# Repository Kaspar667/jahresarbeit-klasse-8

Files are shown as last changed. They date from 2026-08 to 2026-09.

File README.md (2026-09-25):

# Jahresarbeit: Bau einer Kamera-Drohne

Jahresarbeit der 8. Klasse an der Rudolf Steiner Schule Berlin (Dahlem).

Ein selbst gewähltes Projekt aus **Theorie und Praxis**: über mehrere Monate wird
eine Kamera-Drohne entwickelt und gebaut, dokumentiert und am Ende vor der
Schulgemeinschaft präsentiert.

## Aufbau in drei Schritten

Das Projekt nähert sich der fertigen Kamera-Drohne in drei aufeinander aufbauenden
Stufen — von einfach zu komplex:

| Schritt | Projekt | Ordner | Ziel |
|---:|---|---|---|
| 1 | Holz-Bausatz (Amazon) | [`01-holzbausatz/`](01-holzbausatz/) | Erste Erfahrungen: Zusammenbau, Motoren, Propeller, Fliegen lernen |
| 2 | ESP-FLY (ESP32-S3) | [`02-esp-fly/`](02-esp-fly/) | Eigene Flugsoftware verstehen: Firmware bauen, flashen, Sensor & Steuerung |
| 3 | Eigenbau-Drohne | [`03-kamera-drohne/`](03-kamera-drohne/) | Selbst entworfen: gefräster Kohlefaserrahmen, eigene Trägerplatine, bürstenlose Motoren |

## Ordnerstruktur

```
jahresarbeit-drohne/
├── README.md              ← dieses Dokument (Überblick)
├── docs/                  ← schriftliche Ausarbeitung, Notizen, Präsentation
├── 01-holzbausatz/        ← Schritt 1
├── 02-esp-fly/            ← Schritt 2 (enthält Firmware als Git-Submodul)
└── 03-kamera-drohne/      ← Schritt 3
```

## Stand (25.09.2026)

Schritt 1 und 2 sind gebaut und geflogen. Schritt 3 ist **durchgeplant**: Auslegung,
Antrieb, Elektronik und die eigene Trägerplatine sind entschieden und begründet, Motoren
und Regler bestellt. Gebaut ist davon noch nichts — die Kapitel in
[`03-kamera-drohne/`](03-kamera-drohne/) halten fest, *warum* welches Teil gewählt wurde.

## Schriftliche Arbeit

Die Ausarbeitung liegt in [`docs/`](docs/). Jeder Bauschritt hat außerdem eine
eigene `README.md` im jeweiligen Ordner, in der Vorgehen, Probleme und Lösungen
festgehalten werden — das bildet später das Rückgrat der schriftlichen Arbeit.

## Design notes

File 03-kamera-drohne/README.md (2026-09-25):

# Schritt 3 — Eigenbau-Drohne (Abschlusswerk)

Das praktische Hauptwerk der Jahresarbeit: eine Drohne, die **nicht gekauft, sondern
entworfen** wird. Rahmen selbst gefräst, Trägerplatine selbst entworfen und gefräst,
Flugsoftware selbst konfiguriert.

Im Gegensatz zu Schritt 1 (fertiger Bausatz) und Schritt 2 (fertiges Board, eigene
Firmware) wird hier **jedes Teil bewusst ausgewählt und die Auswahl begründet**. Genau
diese Begründungen sind der Stoff der schriftlichen Arbeit — nicht die Bauanleitung.

## Der Stand in einem Absatz

Geplant ist ein **Quadrocopter mit 9 × 9 cm Kohlefaserrahmen**, ausgelegt nicht auf Schub,
sondern auf **Ausdauer**: Ziel sind 15–30 Minuten Flugzeit, realistisch geschätzt 11–19.
Angetrieben von vier bürstenlosen 1204-Motoren an einem gekauften 4-in-1-Regler, gesteuert
von einem **Seeed XIAO ESP32-S3** (demselben Mikrocontroller wie in Schritt 2) mit der
offenen Flugsoftware **ESP-FC**. Dazwischen sitzt eine **selbst entworfene Trägerplatine**,
die auf der CNC-Fräse 1310 hergestellt wird. Motoren und Regler sind bestellt
(23.09.2026), die Steuerungsseite noch nicht.

## Die Kapitel

| Datei | Inhalt |
|---|---|
| [`01-auslegung.md`](01-auslegung.md) | Rahmen, Propellergröße, Flugzeit — warum 9 × 9 cm alles andere festlegt |
| [`02-antrieb.md`](02-antrieb.md) | Motoren, Regler, Akku — und warum es 2S werden musste |
| [`03-elektronik.md`](03-elektronik.md) | XIAO ESP32-S3, ESP-FC, Pinbelegung, Fernsteuerung |
| [`04-traegerplatine.md`](04-traegerplatine.md) | Die eigene Platine: Entwurf, Schaltplan, Bauteile |
| [`05-bestellliste.md`](05-bestellliste.md) | Was bestellt ist, was noch fehlt |
| [`06-bauplan.md`](06-bauplan.md) | Alle Schritte von der Bestellung bis zum ersten Flug |
| [`cad/`](cad/) | Rahmen als 3D-Modell (STEP, DXF zum Fräsen, STL) |

## Die sechs Entscheidungen, um die es geht

Wer die Arbeit schreibt, braucht vor allem diese sechs — jede ist eine Abwägung, keine
Geschmacksfrage.

**1. Ausdauer statt Schub.** Man kann dieselbe Baugröße auf Beschleunigung auslegen
(Renn-Drohne, 2 Minuten Flugzeit) oder auf lange Flugzeit. Entschieden: Ausdauer. Das legt
Akkutyp (Lithium-Ionen-Rundzellen statt LiPo), Propellersteigung und Motorwahl fest.

**2. 9 × 9 cm — und damit keine 3-Zoll-Propeller.** Der Fräsbereich der 1310 gibt die
Rahmengröße vor. Daraus folgt durch reine Geometrie, dass 3-Zoll-Propeller sich
überschneiden würden. Es werden 2,8 Zoll. → [`01-auslegung.md`](01-auslegung.md)

**3. Eigene Steuerplatine statt fertiger Flugsteuerung.** Nicht aus Ehrgeiz: ein Kreisel,
der an fliegenden Drähten hängt, misst die Schwingung der Drähte mit und lässt sich nicht
abstimmen. → [`04-traegerplatine.md`](04-traegerplatine.md)

**4. Zwei Akkuzellen (2S) statt einer.** Folgt zwangsläufig aus Entscheidung 3: getrennte
Regler, wie sie ein eigenes Board braucht, gibt es im Handel erst ab zwei Zellen. Kostet
etwa 15 % Flugzeit — das ist der Preis für den eigenen Entwurf.
→ [`02-antrieb.md`](02-antrieb.md)

**5. Kreisel über I2C, nicht SPI.** Der XIAO hat nur elf nutzbare Anschlüsse. SPI wäre
schneller, würde aber vier davon verbrauchen — dann bliebe kein Platz mehr für Barometer
und Summer. → [`03-elektronik.md`](03-elektronik.md)

**6. Der Ausbau in drei Stufen.** Einen bürstenlosen Regler von Grund auf zu bauen ist ein
eigenes Projekt. Deshalb gestaffelt, und **jede Stufe fliegt für sich**:

- **Stufe 1 — eigene Trägerplatine, gekaufter Regler.** ← *hier stehen wir*
- **Stufe 2 — eigener Regler** mit der offenen AM32-Firmware.
- **Stufe 3 — Gestensteuerung** über Raspberry Pi mit Kamera.

## Die Kamera: erst später (Stand 25.09.2026)

Der Projekttitel heißt „Kamera-Drohne", **Version 1 fliegt aber bewusst ohne Kamera.** Erst
soll das Fluggerät selbst sauber fliegen, dann kommt die Kamera dazu. Geplant ist dann
**analoges FPV**: Nano-Kamera, 5,8-GHz-Videosender (25 mW), Videobrille mit Rekorder.
Das kostet ~8 g und etwa 10 % Flugzeit.

Damit das später ohne Umbau geht, bekommt die Trägerplatine **schon jetzt** einen stärkeren
5-V-Regler (≥ 1,5 A) und einen Anschluss für Kamera und Sender. Kamera und Sender brauchen
keinen GPIO, die Pinbelegung bleibt gleich. Einzelheiten in
[`05-bestellliste.md`](05-bestellliste.md).

Für Stufe 3 (Gestensteuerung) kommt ohnehin eine Kamera am **Boden** dazu, auf einem
Raspberry Pi, der Kaspars Handbewegungen erkennt.

## Was als Nächstes passiert

1. Dicke der vorhandenen Kohlefaserplatte prüfen (soll 2,5 mm sein).
2. Rahmen in CAD zeichnen: 90 × 90 mm, Motorachsen 7,5 mm von den Kanten, vorne Platz für einen späteren Kamerahalter lassen.
3. Trägerplatine layouten und auf der 1310 fräsen.
4. Fehlende Teile nach der [Einkaufsliste](05-bestellliste.md) bestellen, das Kreiselmodul zuerst, ohne das fliegt nichts.
5. Ersten Rahmen fräsen und die Steifigkeit messen (Zielwert unter 6 mm Auslenkung).

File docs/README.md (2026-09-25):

# Schriftliche Ausarbeitung

Hier entsteht der schriftliche Teil der Jahresarbeit.

Vorschlag für die Gliederung:

1. **Einleitung** — Warum eine Kamera-Drohne? Persönliche Motivation.
2. **Grundlagen** — Wie fliegt eine Drohne? (Auftrieb, 4 Motoren, Gyroskop/IMU, Steuerung)
3. **Schritt 1 — Holz-Bausatz** — Aufbau, was funktioniert hat, was nicht.
4. **Schritt 2 — ESP-FLY** — eigene Firmware, Mikrocontroller (ESP32-S3), Sensor, Flashen.
5. **Schritt 3 — Eigenbau-Drohne** — Planung, Bau, Ergebnis. Das umfangreichste Kapitel;
   Material und Begründungen liegen in [`../03-kamera-drohne/`](../03-kamera-drohne/):
   - Auslegung: warum die Rahmengröße alles andere festlegt
   - Antrieb: bürstenlos statt Bürsten, und warum daraus zwei Akkuzellen folgen
   - Elektronik: derselbe Mikrocontroller wie in Schritt 2, andere Software
   - Die eigene Trägerplatine: Entwurf, Schaltplan, Fertigung auf der Fräse
6. **Reflexion** — Was habe ich gelernt? Was würde ich anders machen?
7. **Quellen**

Bilder und Videos gehören in einen Unterordner `docs/bilder/`.

## Hinweis zu Schritt 3

Die Kapiteldateien in `03-kamera-drohne/` sind bewusst so geschrieben, dass jede
Entscheidung eine **Begründung und eine verworfene Alternative** hat. Genau das ist der
Stoff, aus dem die schriftliche Arbeit besteht — eine reine Bauanleitung wäre zu wenig.

Besonders ergiebige Stellen:

- **Geometrie:** dass 3-Zoll-Propeller auf 9 × 9 cm nicht passen, lässt sich vorrechnen.
- **Folgekosten einer Entscheidung:** die eigene Platine erzwingt 2S und kostet dadurch
  ~15 % Flugzeit.
- **Datenblatt gegen Messung:** eine Akkuzelle mit 52 A Angabe schafft real 25 A.
- **Eigene Messung:** Rahmensteifigkeit (1,13 kg am Motorträger, Zielwert unter 6 mm) und
  die tatsächliche Flugzeit im Vergleich zur Vorhersage von 11–19 min.
- **Lehre aus Schritt 1:** warum ein Quadrocopter überhaupt zwei Drehrichtungen braucht —
  der Holz-Bausatz drehte sich ständig um die Hochachse, weil sich die Drehmomente nicht
  aufhoben.

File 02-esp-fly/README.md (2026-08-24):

# Schritt 2 — ESP-FLY (ESP32-S3)

Die [ESP-FLY](https://github.com/Seeed-Projects/Co-Create_ESP-FLY) ist eine winzige
Drohne auf Basis des Mikrocontrollers **Seeed XIAO ESP32-S3**. In diesem Schritt
geht es nicht nur ums Bauen, sondern darum, die **Flugsoftware (Firmware) selbst
zu verstehen, anzupassen und auf die Drohne zu spielen**.

## Was hier drin ist

- **`esp-drone/`** — die Firmware als **Git-Submodul** auf unseren Fork
  [`spieker/esp-drone`](https://github.com/spieker/esp-drone), Branch
  `jahresarbeit-klasse-8`. Hier stehen unsere board-spezifischen Anpassungen.
- **`esp-idf/`** — die Bau-Umgebung von Espressif als **Git-Submodul**,
  fest auf **v5.0** gepinnt (die Version, mit der es funktioniert).
- **`flash.sh`** — spielt die gebaute Firmware auf die Drohne (per USB).
- **`BUILD.md`** — die ausführliche Schritt-für-Schritt-Anleitung.

## Kurzanleitung

Ausführlich in **[BUILD.md](BUILD.md)**. In Kürze:

```bash
# 1. Projekt inkl. Submodule holen (falls noch nicht geschehen)
git submodule update --init --recursive     # laedt esp-drone + esp-idf (~1,7 GB)

# 2. ESP-IDF einmalig einrichten
cd esp-idf && ./install.sh esp32s3 && cd ..

# 3. Firmware bauen
cd esp-drone
. ../esp-idf/export.sh
idf.py set-target esp32s3        # zieht die ESP-FLY-Pins aus sdkconfig.defaults.esp32s3
idf.py build
cd ..

# 4. Drohne per USB anstecken, dann flashen
./flash.sh                       # findet ESP-IDF und Port automatisch
```

Zum Fliegen: Handy ins WLAN `ESP-DRONE_...` (Passwort `12345678`), dann die
**ESP-Drone App** öffnen und verbinden.

## Unsere Anpassungen (das Wichtigste zum Dokumentieren)

Die Standard-Firmware von Espressif geht von *anderen* Pins aus als das
ESP-FLY-Board. Ergebnis: der Bewegungssensor (MPU6050) meldete beim Start
`MPU6050 I2C connection [FAIL]`, und die App konnte sich nicht verbinden.

Lösung — in `esp-drone/sdkconfig.defaults.esp32s3` die richtigen Pins des
ESP-FLY-Boards eingetragen:

| Bauteil | Signal | GPIO |
|---|---|-----:|
| MPU6050 (Sensor) | I2C SDA | 5 |
| MPU6050 (Sensor) | I2C SCL | 6 |
| MPU6050 (Sensor) | INT | 8 |
| Motor 1 | PWM | 7 |
| Motor 2 | PWM | 4 |
| Motor 3 | PWM | 3 |
| Motor 4 | PWM | 1 |

Motortyp: brushed **715**. Danach: `MPU6050 I2C connection [OK]` — Sensor läuft,
App verbindet sich, Drohne fliegt.

> **Lernpunkt:** Software muss zur konkreten Hardware passen. Derselbe Programmcode
> funktioniert erst, wenn er weiß, an welchen Anschlüssen (Pins) des Chips die
> Bauteile wirklich hängen.

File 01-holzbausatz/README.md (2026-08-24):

# Schritt 1 — Holz-Bausatz (Amazon)

Der Einstieg: ein günstiger Drohnen-Bausatz aus Holz.

## Ziel
Erste Erfahrungen mit dem Aufbau einer Drohne sammeln — Rahmen, Motoren,
Propeller, Akku, Steuerung — und das Fliegen üben.

## Zu dokumentieren
- Welcher Bausatz? (Link / Bestellnummer)
- Aufbau: Was war einfach, was schwierig?
- Erster Flugversuch: Wie lief es?
- Was hat dieser Schritt für die nächsten gebracht?

## Fotos
In `bilder/` ablegen.

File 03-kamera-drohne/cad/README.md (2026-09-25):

# CAD: Rahmen

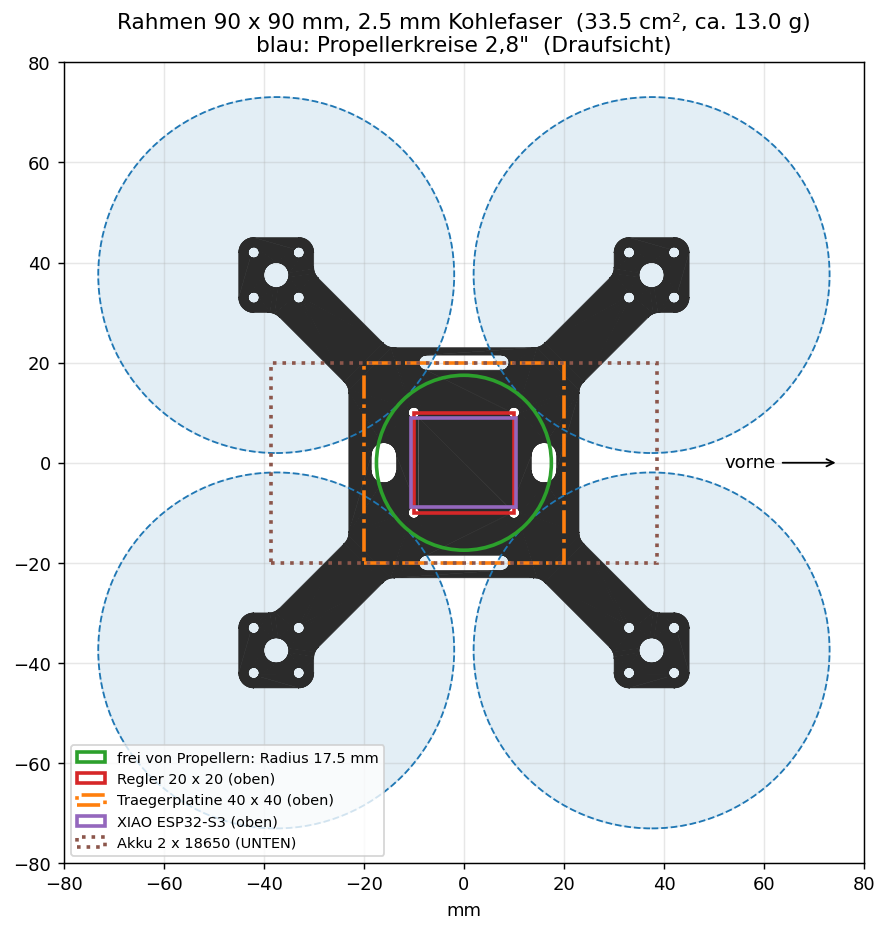
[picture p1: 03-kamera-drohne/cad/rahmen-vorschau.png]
Draufsicht


Erster Entwurf des Rahmens, 25.09.2026. Das Modell wird **aus einem Programm erzeugt**
([`rahmen.py`](rahmen.py), CadQuery). Wer ein Maß ändern will, ändert die Zahl oben in der
Datei und lässt das Programm neu laufen, dann passen alle Dateien wieder zusammen.

| Datei | Wofür |
|---|---|
| `rahmen.step` | 3D-Modell zum Öffnen in Fusion 360 oder FreeCAD |
| `rahmen.dxf` | 2D-Kontur für das Fräsprogramm der CNC 1310 (echte Kreise und Bögen) |
| `rahmen.stl` | zum Anschauen, oder als 3D-Druck-Probeteil |
| `rahmen-vorschau.png` | Draufsicht mit Propellern, Regler, Platine und Akku |

## Die Maße

| | |
|---|---|
| Außenmaß | 90 × 90 × 2,5 mm, Kohlefaser |
| Motorachsen | 7,5 mm vom Rand, also bei ±37,5 mm; Radstand 106 mm |
| Motorträger | 15 × 15 mm, 4 × M2 (Ø 2,2 mm) im 9 × 9-Quadrat, Mittelloch Ø 5 mm für das Wellenende |
| Arme | 11 mm breit, alle Ecken mit 3 mm ausgerundet |
| Rumpf | 46 × 46 mm |
| Regler | 4 × M2 im 20 × 20-Quadrat, mittig |
| Gurtschlitze | 2 × 18 × 3 mm links und rechts, für den Klettgurt des Akkus |
| Kabelschlitze | 8 × 5 mm vorne und hinten: Akkukabel nach oben, vorne Reserve für die Kamera |
| Fläche / Gewicht | 33,5 cm², **ca. 13 g** (Ziel war 12 g) |
| Spalt zwischen Nachbarpropellern | 3,9 mm |

Vorne ist **+X**, also die Seite zwischen zwei Armen.

## Was das Modell gezeigt hat

Beim Einzeichnen der Propellerkreise sind zwei Dinge aufgefallen, die man auf dem Papier
leicht übersieht:

**1. Der Akku muss unter den Rahmen.** Die 2,8"-Propeller überdecken in der Draufsicht fast
die ganze Fläche. Frei bleibt nur ein Kreis mit **17,5 mm Radius** um die Mitte (grün). Der
Akkuhalter ist ~77 × 40 mm groß und 20 mm hoch. Oben auf dem Rahmen würde er in die
Propeller ragen. Unter dem Rahmen stört er nicht, weil die Propeller oben sitzen. Deshalb
die Gurtschlitze: Der Akku wird von unten mit einem Klettgurt angeschnallt.

**2. Die Ecken der Trägerplatine liegen unter den Propellern.** Die Platine (40 × 40 mm) ragt
über den grünen Kreis hinaus. Das geht nur, solange sie **flach** bleibt und tiefer liegt
als die Propeller. Die Motorhöhe am gelieferten Motor nachmessen: Alles, was außerhalb des
grünen Kreises liegt, muss mit Luft unter der Propellerebene bleiben. Der XIAO (lila) liegt
innerhalb des Kreises und darf deshalb höher bauen. Wird es zu eng: Platinenecken
abschrägen.

## Neu erzeugen

```bash
python3 -m venv cadenv
./cadenv/bin/pip install cadquery matplotlib
./cadenv/bin/python rahmen.py
```

## Vor dem Fräsen

- Erst in **Holz oder MDF** probefräsen und einen Motor anschrauben.
- M2-Löcher sind mit 2,2 mm gezeichnet; mit einem 1,5-mm-Fräser spiralförmig ausfräsen.
- Kohlefaser: Maske FFP2/FFP3, Absaugung oder nass fräsen, Fräse abdecken.

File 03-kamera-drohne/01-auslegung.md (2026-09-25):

# Auslegung: Rahmen, Propeller, Flugzeit

*Wie aus einer einzigen Entscheidung — der Rahmengröße — fast alles andere folgt.*

## Der Ausgangspunkt: die Fräse

Der Rahmen soll selbst hergestellt werden, auf der vorhandenen CNC-Fräse **1310**. Deren
Arbeitsbereich ist etwa **13 × 10 cm**. Für ein Werkstück mit Einspannung bleibt eine
Platte von rund **9 × 9 cm**.

Das klingt nach einer Nebensache. Tatsächlich legt diese Zahl die Propellergröße fest, die
Propellergröße legt die Motoren fest, die Motoren legen den Akku fest — und der Akku
bestimmt die Flugzeit. Eine schöne Kette für die schriftliche Arbeit.

## Warum keine 3-Zoll-Propeller passen

Jeder Motor braucht einen Motorträger: das Lochbild misst 9 × 9 mm, plus Rand ergibt das
ein Feld von etwa 15 × 15 mm. Die Motorachse liegt damit mindestens **7,5 mm von der
Plattenkante** entfernt.

Auf einer 90 × 90-mm-Platte sitzen die vier Motorachsen dann auf einem Quadrat von
75 × 75 mm. Zwei benachbarte Propeller haben also 75 mm Achsabstand — und ein 3-Zoll-
Propeller ist **76,2 mm im Durchmesser**. Zwei davon nebeneinander bräuchten 76,2 mm
Abstand, um sich gerade eben nicht zu berühren.

| Motorachse vom Rand | Achsabstand der Nachbarn | Radstand | Spalt bei 2,5" | bei 2,8" | bei 3,0" |
|---|---|---|---|---|---|
| 7,0 mm | 76,0 mm | 107,5 mm | +12,5 mm | +5,0 mm | **−0,2 mm** |
| 7,5 mm | 75,0 mm | 106,1 mm | +11,5 mm | +4,0 mm | **−1,2 mm** |
| 8,0 mm | 74,0 mm | 104,7 mm | +10,5 mm | +3,0 mm | **−2,2 mm** |

Ein negativer Spalt heißt: **die Propellerkreise schneiden einander.** Das geht nicht — die
Blätter würden sich zerschlagen.

Machbar sind **2,5 Zoll** (63,5 mm, komfortable 11,5 mm Spalt) oder **2,8 Zoll** (71 mm,
4 mm Spalt). 4 mm sind eng, aber mehr, als viele gekaufte Rahmen dieser Klasse bieten.
Der Radstand liegt in beiden Fällen bei etwa 106 mm.

**Entschieden: 2,8 Zoll.** Der größere Propeller ist bei gleichem Schub sparsamer, und
darum geht es bei einem Ausdauergerät.

### Der Ausweg, den wir nicht nehmen

Echte 3-Zöller wären möglich, wenn man die **Arme getrennt fräst** und an eine
9 × 9-Mittelplatte schraubt — der Fräsbereich begrenzt ja das Einzelteil, nicht die fertige
Baugruppe. Dagegen spricht: Schraubverbindungen kämen genau an die Stelle, die in allen
veröffentlichten Bruchtests **zuerst versagt** — den Übergang Arm zu Rumpf. Der Gewinn
wären etwa 60 Sekunden Flugzeit. Für Version 1 nicht empfohlen.

## Propeller: zwei oder drei Blätter?

**Was die Physik sagt:** Weniger Blätter sind sparsamer, weil jedes Blatt in der
Verwirbelung des vorhergehenden arbeitet. Mehr Blätter geben bei begrenztem Durchmesser
mehr Schub und laufen ruhiger, ziehen dafür mehr Strom. Für Ausdauer spricht also
Zweiblatt.

**Was die Messdaten sagen:** Dasselbe. Alle drei Ausdauer-Referenzbauten der Messseite
lithiumionfpv.com fliegen einen Zweiblatt-Propeller (Gemfan Hurricane 3018).

**Was der Markt sagt:** Etwas anderes. In 2,8 Zoll gibt es praktisch nur Dreiblatt. Ein
2,8"-Zweiblatt war nicht auffindbar; Zweiblätter gibt es reichlich in 3 Zoll — und 3 Zoll
passt nicht.

**Warum es kaum eine Rolle spielt:** Durchgerechnet auf unser Gerät bei 160 g Abflug-
gewicht ist der Unterschied **etwa eine Minute**:

| Variante | Abfluggewicht | geschätzte Flugzeit |
|---|---|---|
| 2,8" **Dreiblatt** (gewählt) | 160 g | **11–19 min** |
| 2,8" Zweiblatt (nicht lieferbar) | 160 g | 12–20 min |
| 2,5" Zweiblatt | 160 g | 11–18 min |
| 3" Zweiblatt mit angeschraubten Armen | 165 g | 12–20 min |

**Entschieden: HQProp T2.8×1.6×3 (2816), 1,5-mm-Bohrung, Dreiblatt.** Die Steigung 1,6"
auf 2,8" ergibt ein Steigungsverhältnis von 0,57 — fast dasselbe wie beim bewährten 3018
(0,60), passt also zum ruhigen Reiseprofil.

Ein Nebeneffekt hilft uns hier sogar: **Dreiblätter laufen vibrationsärmer.** Unser Kreisel
hängt am I2C-Bus und hat damit eine begrenzte Abtastrate — je ruhiger der Rahmen, desto
besser für die Flugregelung.

> **Wichtig:** Propeller werden in **beiden Drehrichtungen** gebraucht (CW und CCW).
> Genau daran ist der Holz-Bausatz aus Schritt 1 gescheitert — er drehte sich ständig um
> die Hochachse, weil die Drehmomente sich nicht aufhoben. Mindestens drei Sätze Ersatz
> mitbestellen.

## Der Rahmen

- **Material: 2,5 mm 3K-Kohlefaser**, einteilig, 90 × 90 mm, Zielgewicht 12 g.
- Motorachsen 7,5 mm von den Kanten, **Lochbild 9 × 9 mm M2** — dieses Lochbild haben alle
  in Frage kommenden Motoren, die Bohrungen sind also unabhängig von der endgültigen
  Motorwahl.
- **Großzügige Ausrundungen** am Übergang Arm zu Rumpf, keine scharfen Innenecken. Dort
  brechen alle getesteten Rahmen zuerst.
- Die Akkuzellen hängen **unter** dem Rahmen, im Halter mit Kupferkontakten (gemessen besser
  als gekaufte Messingkontakte), mit Klettgurt durch zwei Schlitze. Oben würden sie in die
  Propeller ragen, das hat das CAD-Modell gezeigt. → [`cad/`](cad/)

> **Warum 2,5 mm und nicht 2 mm:** Ein einteiliger 3-Zoll-Carbonrahmen riss in den
> ausgewerteten Tests bei 2 mm Materialstärke **ohne echten Absturz** und wurde daraufhin
> auf 2,5 mm erhöht. Bei nur 2 mm vorhandener Platte müssten die Arme gedoppelt werden.

> **Achtung beim Fräsen:** Kohlefaserstaub ist gesundheitsschädlich **und elektrisch
> leitfähig**. FFP2/FFP3-Maske, Absaugung oder nass fräsen, und die Elektronik der Fräse
> abdecken. Einschneider aus Hartmetall oder mit Diamantverzahnung, 1–2 mm, hohe Drehzahl,
> mehrere flache Zustellungen. M2-Löcher (2,1 mm) lassen sich mit einem 1,5-mm-Fräser
> spiralförmig ausfräsen.

> **Und noch eins:** Kohlefaser leitet Strom. Alles Blanke auf dem Rahmen mit flüssigem
> Isolierband isolieren, sonst gibt es Kurzschlüsse.

### Prüfung nach dem Fräsen

Den halben Rahmen einspannen, **1,13 kg am Motorträger** anhängen und die Auslenkung
messen. **Zielwert: unter 6 mm.** Das ist ein schöner, überprüfbarer Versuch für die
schriftliche Arbeit — mit Messwert und Vergleich zu veröffentlichten Rahmen.

## Erwartete Flugzeit

Die Schätzung entsteht durch Hochrechnung von gemessenen Referenzbauten über die
physikalische Beziehung: **Schwebeleistung ∝ Masse^1,5 / √Propellerfläche.** Schwerer
kostet also überproportional, größere Propeller helfen.

| Aufbau | Abfluggewicht | geschätzte Flugzeit |
|---|---|---|
| Idealfall 1S-AIO (fertige Elektronik, 1 Zelle) | 88 g | 15–24 min |
| **Unser Aufbau: 2S, eigene Platine, 2 × 18650** | **~160 g** | **11–19 min** |
| dito mit 21700-Zellen | ~207 g | 13–21 min |

Zwei Dinge sind daran bemerkenswert und gehören in die Arbeit:

**Größere Zellen bringen fast nichts.** Die 21700 speichert mehr Energie, wiegt aber auch
mehr — und das Mehrgewicht frisst den Gewinn fast auf. Ein Gegenbeispiel zur Intuition
„größerer Akku = längerer Flug".

**Der wirkliche Hebel ist das Trockengewicht.** Jedes Gramm, das nicht fliegen muss,
verlängert den Flug überproportional. Deshalb: leichte Module statt großer Platinen, kurze
Kabel, sparsamer Zellhalter.

> Das sind **Abschätzungen aus fremden Messwerten, keine eigenen Messungen** — als
> Zielkorridor brauchbar, nicht als Zusage. Die tatsächliche Flugzeit selbst zu messen und
> mit dieser Vorhersage zu vergleichen, wäre ein gutes Schlusskapitel.

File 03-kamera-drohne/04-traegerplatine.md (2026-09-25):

# Die eigene Trägerplatine

*Das Herzstück des Eigenbaus: eine selbst entworfene Leiterplatte, gefräst auf der
CNC 1310.*

Sie sitzt zwischen dem XIAO ESP32-S3 und dem 4-in-1-Regler und ersetzt an einer Stelle:
Kreiselmodul samt Verkabelung, 5-V-Reglermodul, Spannungsteiler und Steckerchaos.

## Warum überhaupt eine eigene Platine

Nicht aus Ehrgeiz, sondern weil die Alternative schlechter fliegt:

> **Ein Kreisel an fliegenden Drähten ist der häufigste Grund für eine Drohne, die sich
> nicht abstimmen lässt.**

Die Flugregelung filtert die Vibrationen heraus, die der Sensor meldet. Sitzt der Sensor
wackelig an Kabeln, misst er die Schwingung der Kabel mit — und die Regelung filtert dann
gegen ein Problem an, das der Aufbau selbst erzeugt. Ein starr und definiert montierter
Sensor ist die Grundlage für alles Weitere.

Die Platine ist dadurch leichter als die Summe der Einzelteile, und sie ist der eigene
Entwicklungsanteil, den eine Jahresarbeit braucht.

## Die Fertigung bestimmt den Entwurf

> **Die 1310 fräst einseitige Platinen ohne durchkontaktierte Löcher**, mit Bahnbreiten um
> 0,2–0,3 mm.

Das hat eine harte Folge: **Ein nackter Sensorchip im QFN- oder LGA-Gehäuse ist damit nicht
sinnvoll bestückbar.** Sein Anschlussraster misst 0,5 mm, und unter dem Bauteil kann ohne
Durchkontaktierungen nichts geroutet werden.

**Die Lösung: fertige Sensormodule aufsetzen.** Die Platine bekommt Lötpads im
2,54-mm-Raster für ein MPU-6050- und ein BMP280-Modul. Die werden **flach und starr**
aufgelötet oder auf kurze Stiftleisten gesteckt — nicht an Kabeln. Mit gefrästen Bahnen
problemlos machbar, und es erreicht das Wesentliche: definierte, steife Sensormontage.

Wer später den nackten Chip will, lässt die Platine industriell fertigen (JLCPCB o.ä.).
Für Stufe 2 (eigener Regler) wird das ohnehin nötig.

## Sensor für Sensor

### Kreisel und Beschleunigungssensor — Pflicht

Ohne ihn gibt es keine Flugregelung. **Gewählt: MPU-6050 über I2C** — nicht weil er der
beste ist, sondern weil ein SPI-Kreisel vier Anschlüsse kostet und dann kein Platz mehr für
Barometer und Summer bliebe. Begründung ausführlich in
[`03-elektronik.md`](03-elektronik.md).

### Barometer — ja, klar

**Kostet null zusätzliche Anschlüsse** (er hängt am selben I2C-Bus) und schaltet die
**Höhenhaltung** frei. Gewählt: **BMP280**.

> Für jemanden, der zum ersten Mal einen bürstenlosen Quadrocopter fliegt, ist Höhenhaltung
> kein Luxus, sondern der Unterschied zwischen „schwebt" und „hüpft". Und bei der
> Vorführung der Jahresarbeit will man die Höhe nicht von Hand halten müssen.

**Einbau:** Der Drucksensor muss vor Propellerwind und vor Licht geschützt werden — beides
verfälscht die Messung. Ein Tropfen **offenzelliger Schaumstoff** darüber. Nicht zukleben,
er muss den Umgebungsdruck noch messen können.

### Magnetometer (Kompass) — nein

Kostet ebenfalls null Anschlüsse, nützt aber **ohne GPS praktisch nichts**: Der Kompass
dient der Navigation, nicht der Lageregelung. Dazu säße er wenige Zentimeter neben
Leitungen, durch die 36 A fließen — die Störung wäre größer als der Nutzen.

### GPS — nicht in Version 1, aber Pads vorsehen

Drei Gründe dagegen: Es bräuchte eine eigene UART, also zwei Anschlüsse, die nicht frei
sind. Ein Modul wiegt 5–10 g, bei 164 g Abfluggewicht also 3–6 %. Und der eigentliche
Nutzen — die Rückkehrautomatik — setzt ein sauber abgestimmtes Fluggerät voraus, das wir am
Anfang nicht haben.

Aber: **zwei unbestückte Lötpads für RX/TX plus 5 V und Masse kosten nichts** und lassen
die Tür offen. Entfällt später der Summer, ist GPS nachrüstbar.

### Strommessung — Messpad statt Anschluss

Der HAKRC hat einen Strommesser eingebaut. Sein Ausgang bräuchte einen ADC-Anschluss, den
wir für die **Spannung** verwenden — bei Lithium-Ionen-Zellen ist die
Tiefentladungsgrenze das, was man wirklich überwachen muss. Den Stromausgang führen wir auf
ein **Messpad**: kostet nichts und macht die Messung am Boden zugänglich.

## Was sonst auf die Platine gehört

| Funktion | Warum |
|---|---|
| **5-V-Schaltregler** aus 2S (6,0–8,4 V) | der HAKRC hat **kein BEC**; versorgt XIAO, Empfänger, Sensoren |
| **Schottky-Diode** im 5-V-Zweig | verhindert Rückspeisung, wenn USB und Akku gleichzeitig hängen |
| **Spannungsteiler 10 kΩ / 5,1 kΩ** | Akkuspannung messen, Tiefentladungswarnung |
| **Stützkondensator** 220–470 µF / 25 V | fängt die Spannungsspitzen der Regler ab |
| **Summer** | Warnung bei leerem Akku **und Suchhilfe nach dem Absturz** — beides praktisch unverzichtbar |
| **Lochbild 20 × 20 mm M2** | passend zum Regler; Softmount mit Gummitüllen zum Rahmen |
| **Messpads** für GND, 3V3, 5V, VBAT, Strom | Fehlersuche mit dem Multimeter, und gut für die Doku |
| **Steckverbinder statt Lötstellen**, wo möglich | nach einem Absturz tauschen statt entlöten |

> Das **Softmount** ist kein Beiwerk, sondern die zweite Hälfte der Antwort auf „warum eine
> eigene Platine": Sensor starr auf der Platine, Platine weich gegen den Rahmen.

## Der Schaltplan

Schaltplan der Trägerplatine

*(Auch als [PNG](bilder/traegerplatine-schaltplan.png).)*

### Grundgedanke: der große Strom läuft nicht über unsere Platine

Das Wichtigste vorweg, weil es den ganzen Entwurf vereinfacht: **Akku und Motorphasen gehen
direkt an den Regler, nicht über unsere Platine.** Dort fließen im Vollgas ~36 A — die
wollen wir nicht auf einer gefrästen Leiterplatte haben.

Unsere Platine zapft am Regler nur `VBAT` und `GND` mit einem dünnen Aderpaar ab und zieht
daraus wenige hundert Milliampere. Alle Bahnen darauf sind Signal- oder
Kleinleistungsbahnen.

```
   Akku (2S) --XT30--> Regler BAT+/BAT-   (dort C1 = 470 uF direkt an die Pads)
                              |
                              +-- duennes Aderpaar --> unsere Platine (VBAT, GND)
                              |
                              +-- Motorphasen --> 4 Motoren
```

### Netzliste

| Netz | Von | Nach |
|---|---|---|
| **VBAT** (6,0–8,4 V) | Regler BAT+ | U4 Buck IN+, R1, TP_VBAT |
| **GND** | Regler BAT− | alles |
| **+5V** | U4 Buck OUT+ | C3, D1 Anode, J3-1 (ELRS VCC), J5-1 (Kamera/VTX), BZ1+, TP_5V |
| **+5V_MCU** | D1 Kathode | U1 Pin `5V` |
| **+3V3** | U1 Pin `3V3` | U2 VCC, U3 VCC, TP_3V3 |
| **VSENSE** | R1 / R2 Mittelpunkt | U1 `D9` (GPIO8), C2 |
| **I2C_SDA** | U1 `D4` (GPIO5) | U2 SDA, U3 SDA |
| **I2C_SCL** | U1 `D5` (GPIO6) | U2 SCL, U3 SCL |
| **M1_SIG** | U1 `D0` (GPIO1) | J2-1 → Regler S1 |
| **M2_SIG** | U1 `D1` (GPIO2) | J2-2 → Regler S2 |
| **M3_SIG** | U1 `D3` (GPIO4) | J2-3 → Regler S3 |
| **M4_SIG** | U1 `D8` (GPIO7) | J2-4 → Regler S4 |
| **RX_IN** (CRSF) | J3-3 (ELRS TX) | U1 `D7` (GPIO44) |
| **RX_OUT** (Telemetrie) | U1 `D6` (GPIO43) | J3-4 (ELRS RX) |
| **BUZZ_CTL** | U1 `D10` (GPIO9) | SJ1 → R3 → Q1 Gate |
| **BUZZ_LOW** | Q1 Drain | BZ1− |
| **GPS_RX** (unbestückt) | U1 `D2` (GPIO3) | J4-3 |
| **GPS_TX** (unbestückt) | SJ1 Alternativstellung | J4-4 |
| **I_SENSE** | Regler Stromausgang | TP_ISENSE (**nicht** am Mikrocontroller) |

### Stückliste

| Pos | Bauteil | Wert / Typ | Bemerkung |
|---|---|---|---|
| U1 | XIAO ESP32-S3 | — | auf 2 × 7-polige Buchsenleisten 2,54 mm, steckbar |
| U2 | Kreiselmodul | MPU-6050 (GY-521) | 8-polig, flach und starr auflöten |
| U3 | Barometermodul | BMP280, I2C-Ausführung | 4-polig |
| U4 | Abwärtsregler | 5 V fest, **≥ 1,5 A** | z.B. Pololu D24V22F5; Reserve für die spätere Kamera + Videosender |
| D1 | Schottkydiode | SS14 / B5819W | im 5-V-Zweig zum XIAO |
| D2 | Freilaufdiode | 1N4148 | nur bei magnetischem Summer nötig |
| Q1 | N-Kanal-MOSFET | 2N7002, SOT-23 | schaltet den Summer |
| R1 | Widerstand | 10 kΩ, 0805 | Spannungsteiler oben |
| R2 | Widerstand | 5,1 kΩ, 0805 | Spannungsteiler unten |
| R3 | Widerstand | 100 Ω, 0805 | Gatewiderstand |
| R4 | Widerstand | 10 kΩ, 0805 | Gate nach Masse |
| R5, R6 | Widerstand | 4,7 kΩ, 0805 | I2C-Pull-ups, **unbestückt** (Module bringen eigene mit) |
| C1 | Elko | 470 µF / 25 V, Low-ESR | **an die Akkupads des Reglers**, nicht auf unsere Platine |
| C2 | Kondensator | 100 nF, 0805 | am Spannungsteiler |
| C3 | Kondensator | 10 µF, 0805 | am 5-V-Ausgang |
| BZ1 | Summer | aktiv, 5 V, 12 mm | mit eigener Tonerzeugung |
| J2 | Stiftleiste | 6-polig 2,54 | zum Regler: S1–S4, GND, I_SENSE |
| J3 | Stiftleiste | 4-polig 2,54 | ELRS: 5V, GND, TX, RX |
| J4 | Lötpads | 4-polig, **unbestückt** | GPS für später |
| J5 | Stiftleiste | 2-polig 2,54 | für die spätere Kamera + Videosender: 5V, GND |
| SJ1 | Lötbrücke | — | D10 wahlweise auf Summer **oder** GPS-TX |
| TP1–TP5 | Messpads | — | GND, 3V3, 5V, VBAT, I_SENSE |
| — | Bohrungen | 4 × Ø2,2 mm, Raster 20 × 20 mm | M2, passend zum Regler |

## Die vier Stellen, an denen man es falsch machen kann

### 1. Der Spannungsteiler

R1 = 10 kΩ, R2 = 5,1 kΩ ergibt ein Teilerverhältnis von 0,338. Bei vollen 8,4 V kommen
**2,84 V** am Messeingang an. Der ESP32-S3 verträgt dort etwa 0–3,1 V — passt mit etwas
Luft.

> **Niemals den Akku direkt an einen Anschluss des Mikrocontrollers legen.** 8,4 V an einem
> 3,3-V-Eingang zerstören den Chip.

In ESP-FC wird der Faktor über `vbat_scale` abgeglichen; am besten mit dem Multimeter
gegenmessen und den Wert anpassen.

### 2. Die Diode D1 und der USB-Konflikt

Der XIAO kann über USB **und** über den 5-V-Anschluss versorgt werden. Beides gleichzeitig
ohne Entkopplung ist eine Einladung zum Rückspeisen — der Schaltregler würde in den
USB-Anschluss des Rechners drücken. **D1 lässt Strom nur vom Schaltregler zum XIAO.**

Der Spannungsabfall von ~0,35 V an der Diode ist unkritisch: Der XIAO braucht am
5-V-Anschluss nur mehr als etwa 4 V für seinen internen 3,3-V-Regler.

### 3. Sensoren an 3V3, nicht an 5V

Kreisel und Barometer hängen am **3V3-Anschluss des XIAO**. Damit laufen sie auch, wenn nur
das USB-Kabel steckt — man kann also am Schreibtisch kalibrieren und einstellen, ohne den
Akku anzuschließen. Eine kleine Entscheidung mit großem Komfortgewinn.

Der ELRS-Empfänger hängt dagegen am 5-V-Netz; zum Binden muss der Akku dran sein oder 5 V
am Messpad eingespeist werden.

### 4. Das Summer-Gate nach Masse

R4 zieht das Gate von Q1 beim Einschalten nach Masse. **Ohne diesen Widerstand piepst der
Summer, solange der Mikrocontroller startet** und seine Anschlüsse noch undefiniert sind.
Ein Bauteil für wenige Cent, das viel Ärger spart. Ob ESP-FC den Ausgang aktiv-hoch oder
aktiv-niedrig schaltet, stellt man mit `buzzer_inverted` ein.

## Hinweise für Layout und Fräsen

- **Einseitig, keine Durchkontaktierungen.** Zwei bis drei Drahtbrücken sind normal und
  völlig in Ordnung — besser eine saubere Brücke als eine gequälte Leiterführung.
- Massefläche auf der einen Lage, großzügig. Signalbahnen 0,3 mm, VBAT- und 5-V-Bahnen
  mindestens 0,8 mm.
- **Das Kreiselmodul in die Mitte der Platine**, möglichst nah an der Drehachse des
  Quadrocopters und flach aufliegend. Nicht an den Rand, nicht auf lange Stiftleisten.
- **Den Schaltregler weit weg vom Kreisel** — er schaltet mit einigen hundert Kilohertz und
  strahlt ein.
- Platinengröße etwa **40 × 40 mm**, Lochbild 20 × 20 mm mittig. **Achtung:** Die Ecken liegen
  unter den Propellern (siehe [`cad/`](cad/)). Außerhalb von 17,5 mm um die Mitte muss die
  Platine flach bleiben und unter der Propellerebene liegen; der XIAO gehört in die Mitte.
- **Auf 1,0 mm FR4 fräsen statt 1,6 mm** — spart rund 1,8 g.

## Gewicht, ehrlich gerechnet

| | |
|---|---|
| Leiterplatte 40 × 40 mm, 1,0 mm FR4 | ~3,0 g |
| MPU-6050-Modul | ~2,0 g |
| BMP280-Modul | ~0,5 g |
| Schaltreglermodul | ~1,5 g |
| Buchsen- und Stiftleisten, Kleinteile | ~1,5 g |
| Summer | ~1,5 g |
| **Summe** | **~10 g** |

Im ursprünglichen Budget standen 5 g Platine + 1,5 g Kreisel = 6,5 g. Es werden also **rund
3,5 g mehr**, das Abfluggewicht steigt auf ~164 g, die Flugzeitschätzung rutscht von 11–19
auf **11–18 min**. Kein Drama — aber genau der Grund, warum 1,0-mm-Material und kleine
Module sich lohnen.

## Was vor dem Löten noch zu klären ist

1. **Pad-Beschriftung des HAKRC.** Liegt noch nicht vor, der Regler ist unterwegs. Vor dem
   Layout am gelieferten Bauteil prüfen: Heißen die Signalpads S1–S4 oder M1–M4, wo liegt
   GND, ist ein Stromausgang herausgeführt?
2. **Ausgangsspannung des Schaltreglers.** Bei einstellbaren Modulen (MP1584) **vor dem
   Einbau** auf 5,0 V trimmen und nachmessen. Ein falsch eingestelltes Modul zerstört den
   XIAO.
3. **Verträgt der ELRS-Empfänger 5 V am Eingang?** Die meisten Nano-Empfänger ja, einige
   wollen 3,3 V. Datenblatt prüfen, bevor J3 verdrahtet wird.

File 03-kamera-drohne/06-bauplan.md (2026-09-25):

# Bauplan: Von der Bestellung bis zum ersten Flug

*Stand 25.09.2026. Die Reihenfolge ist Absicht: Erst wird jedes Teil **einzeln** getestet,
dann zusammengebaut. Wenn am Ende etwas nicht geht, weiß man so, dass es nicht an den
Einzelteilen liegt.*

Zu jedem Schritt **Fotos machen und kurz notieren**, was geklappt hat und was nicht. Das
wird später die schriftliche Arbeit.

## Phase A: Während die Teile unterwegs sind (2–3 Wochen)

- [ ] **1. Kohlefaserplatte messen.** Soll 2,5 mm dick sein, Messschieber an mehreren
      Stellen.
- [x] **2. Rahmen im CAD zeichnen.** Erster Entwurf liegt in [`cad/`](cad/) (STEP, DXF, STL).
      In Fusion 360 oder FreeCAD öffnen und anschauen; Maße bei Bedarf in `rahmen.py`
      ändern.
- [ ] **3. Probefräsen in Holz oder MDF.** Billig, ungefährlich, und man sieht, ob Maße und
      Fräsprogramm stimmen, bevor die teure Kohlefaser dran ist. Probeweise einen Motor
      anschrauben, sobald er da ist.
- [ ] **4. Trägerplatine in KiCad zeichnen** nach dem Schaltplan in
      [`04-traegerplatine.md`](04-traegerplatine.md). Den Stecker zum Regler (J2) erst
      festlegen, wenn der Regler da ist, weil die Pad-Beschriftung noch unbekannt ist.
- [ ] **5. Software vorbereiten:** VS Code mit PlatformIO und den Betaflight-Configurator
      installieren, [ESP-FC](https://github.com/rtlopez/esp-fc) herunterladen und einmal
      für den ESP32-S3 bauen.
- [ ] **6. Mit den Eltern die Haftpflichtversicherung klären.**

## Phase B: Teile sind da, jedes einzeln testen

- [ ] **7. Wareneingang prüfen:** Motoren 6500 KV, Regler 15 A, alles vollständig?
- [ ] **8. Fliegen üben im Simulator.** Die Pocket lässt sich per USB als Joystick an den
      Computer anschließen. Mit einem FPV-Simulator (z.B. Liftoff, Uncrashed) üben. Eine
      bürstenlose Drohne reagiert viel schneller als die aus Schritt 1 und 2, und im
      Simulator kostet ein Absturz nichts.
- [ ] **9. Sensor-Test auf dem Steckbrett:** XIAO + MPU-6050 + BMP280 mit Kabeln auf einem
      Steckbrett verbinden, ESP-FC flashen, die Pins einstellen (Befehle in
      [`03-elektronik.md`](03-elektronik.md)). Im Configurator muss sich das 3D-Modell
      mitbewegen, wenn man das Steckbrett kippt. **Das prüft den Schaltplan, bevor die
      Platine gefräst wird.**
- [ ] **10. Empfänger binden:** ELRS-Empfänger dazu, mit der Pocket binden, im Reiter
      *Receiver* prüfen, dass sich alle Balken mit den Knüppeln bewegen.
- [ ] **11. 5-V-Regler testen:** an ein Netzteil oder den Akku, **Ausgang mit dem
      Multimeter messen**. Erst wenn da 5,0 V stehen, darf etwas anderes dran.
- [ ] **12. Motoren am Regler testen:** Motoren an den Regler löten, Kondensator an die
      Akkupads, Akku **über den Smoke-Stopper** anschließen. **Ohne Propeller!** Im Reiter
      *Motors* jeden Motor einzeln langsam drehen lassen: Richtige Reihenfolge? Richtige
      Drehrichtung?

## Phase C: Bauen

- [ ] **13. Rahmen aus Kohlefaser fräsen.** Maske (FFP2/FFP3), Absaugung oder nass fräsen,
      Fräse abdecken. Danach **Biegetest**: halben Rahmen einspannen, 1,13 kg an den
      Motorträger hängen, Auslenkung messen (Ziel unter 6 mm).
- [ ] **14. Platine fräsen und bestücken.** Vor dem Einstecken des XIAO **alle Messpads mit
      dem Multimeter prüfen**: kein Kurzschluss zwischen 5 V und GND, VBAT richtig.
- [ ] **15. Zusammenbau:** Motoren an den Rahmen, Regler und Platine mit Gummitüllen
      (Softmount), Akkuhalter oben, alle blanken Stellen isolieren (Kohlefaser leitet!).
- [ ] **16. Einstellen im Configurator:**
      - Beschleunigungssensor auf ebener Fläche kalibrieren
      - Schalter auf der Pocket belegen: **Scharfschalten (Arm)**, Flugmodus *Angle*
        (selbst ausgleichend), Höhenhaltung
      - Akkuspannung mit dem Multimeter vergleichen und `vbat_scale` anpassen
      - **Failsafe testen:** Pocket ausschalten, die Motoren müssen stoppen. Ohne das nicht
        fliegen!

## Phase D: Fliegen

- [ ] **17. Propeller drauf, richtige Richtung prüfen.** CW-Propeller auf die
      CW-Motoren, CCW auf die CCW-Motoren. Falsch herum hebt die Drohne nicht ab oder
      überschlägt sich sofort.
- [ ] **18. Erster Flug:** draußen, große Wiese, keine Menschen in der Nähe, im Modus
      *Angle*, nur knapp über dem Boden schweben. Jemand dabei, der aufpasst.
- [ ] **19. Abstimmen:** Wenn die Drohne wackelt oder schwingt, PID-Werte anpassen. Die
      Blackbox (Flugschreiber) hilft herauszufinden, woran es liegt.
- [ ] **20. Messen für die Arbeit:** Abfluggewicht wiegen, Flugzeit mit der Stoppuhr messen
      und mit der Vorhersage (11–18 min) vergleichen. Das ist ein gutes Schlusskapitel.

## Danach

- Kamera nachrüsten (Teile in [`05-bestellliste.md`](05-bestellliste.md), „Später: Kamera")
- Regler-Firmware auf Bluejay umflashen
- Stufe 2: eigener Regler, Stufe 3: Gestensteuerung

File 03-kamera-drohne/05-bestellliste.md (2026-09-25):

# Bestellliste

*Stand 25.09.2026. **Version 1 fliegt erst einmal ohne Kamera**, sie wird später nachgerüstet
(siehe „Später: Kamera" unten). Lieferzeit aus China erfahrungsgemäß zwei bis drei Wochen,
bei deutschen FPV-Händlern (FPV24, Quadmula, n-Factory) wenige Tage, dafür etwas teurer.*

Preise sind grobe Richtwerte.

## Bestellt

- [x] **4 × Happymodel EX1204, 6500 KV**: AliExpress (DronePartsPro), 36,39 € + 4,86 € Versand
- [x] **2 × HAKRC 4-in-1-Regler 15 A, 2–4S, 20 × 20 mm**: AliExpress (Wing Pules Model),
      20,99 € + 4,35 € Versand

> **Bei Ankunft prüfen:** Motoren müssen **6500 KV** sein (nicht 5000 KV), Regler **15 A**
> (nicht 25 A), und vier Motoren im Karton.

## Einkaufsliste

### 1. Sensoren und Flugrechner: zuerst bestellen, ohne die fliegt nichts

| ✓ | Teil | Worauf achten | ca. |
|---|---|---|---|
| [ ] | **MPU-6050-Modul (GY-521)** | 2–3 Stück kaufen, sind billig und gehen beim Löten gern kaputt | 3–8 € |
| [ ] | **BMP280-Modul, I2C, 3,3 V** | nicht BME280/BMP180 verwechseln; 2–3 Stück | 3–8 € |
| [ ] | **Seeed XIAO ESP32-S3** | neu kaufen, dann bleibt die ESP-FLY flugfähig | ~9 € |

### 2. Fernsteuerung (ELRS 2,4 GHz)

| ✓ | Teil | Worauf achten | ca. |
|---|---|---|---|
| [ ] | **RadioMaster Pocket, ELRS-Version** | **nicht** die CC2500-Version | 70–100 € |
| [ ] | **2 × 18650 für die Pocket** | die Pocket läuft mit 18650-Zellen, die sind nicht dabei; normale Qualitätszellen reichen hier | ~10 € |
| [ ] | **ELRS-Empfänger 2,4 GHz**, z.B. RadioMaster RP1 oder Happymodel EP2 | **5-V-tauglich** (Datenblatt!), 2,4 GHz wie der Sender | 10–15 € |

### 3. Akku und Laden

| ✓ | Teil | Worauf achten | ca. |
|---|---|---|---|
| [ ] | **4 × 18650 Eve 30PL oder Ampace JP30** | **nur diese beiden** schaffen die ~36 A; 4 Stück = 2 Sätze zum Wechseln | 25–35 € |
| [ ] | **Zellhalter 2 × 18650 in Reihe** | mit **Kupferkontakten**, leicht | ~5 € |
| [ ] | **Ladegerät für 18650**, 4 Schächte (z.B. XTAR, Nitecore) | Zellen **einzeln** laden, dann sind sie automatisch ausgeglichen | 20–30 € |

### 4. Trägerplatine

| ✓ | Teil | Worauf achten | ca. |
|---|---|---|---|
| [ ] | **5-V-Schaltregler, fest 5 V, mind. 1,5 A**, z.B. Pololu D24V22F5 | ohne Kamera würden 500 mA reichen; die 1,5 A kosten kaum mehr und machen die Kamera später nachrüstbar | ~12 € |
| [ ] | Schottky-Diode SS14 / B5819W | | |
| [ ] | MOSFET 2N7002 (SOT-23) | für den Summer | |
| [ ] | Widerstände 0805: 10 kΩ (2×), 5,1 kΩ, 100 Ω | Spannungsteiler, Gate | |
| [ ] | Kondensatoren 0805: 100 nF, 10 µF | | |
| [ ] | **Elko 470 µF / 25 V, Low-ESR** | an die Akkupads des Reglers | ~1 € |
| [ ] | Summer, **aktiv**, 5 V, 12 mm | aktiv = macht den Ton selbst | ~1 € |
| [ ] | Buchsenleisten 2 × 7-polig, Stiftleisten 2,54 mm | für den steckbaren XIAO | ~3 € |
| [ ] | **Platinenmaterial FR4, einseitig, 1,0 mm** | 1,0 statt 1,6 mm spart ~1,8 g | ~5 € |
|  | *Kleinteile zusammen* | am besten bei einem Elektronikhändler in einer Bestellung | ~10 € |

### 5. Propeller, Kabel, Schrauben

| ✓ | Teil | Worauf achten | ca. |
|---|---|---|---|
| [ ] | **HQProp T2.8×1.6×3 (2816), 1,5-mm-Bohrung** | **6 Paar, CW und CCW**, genau daran ist Schritt 1 gescheitert | ~15 € |
| [ ] | XT30-Stecker (Paare) | | ~5 € |
| [ ] | Silikonlitze 18 AWG (Akku) und 26–28 AWG (Signal) | | ~5 € |
| [ ] | M2-Schrauben, M2-Abstandshülsen, **Gummitüllen** | Motoren 9 × 9, Regler 20 × 20, Softmount | ~10 € |
| [ ] | Flüssiges Isolierband, Schrumpfschlauch | Kohlefaser leitet Strom! | ~10 € |
| [ ] | **Smoke-Stopper** (oder Sicherung) fürs erste Einschalten | verhindert, dass ein Lötfehler gleich alles abbrennt | ~10 € |
| [ ] | Kohlefaserplatte 2,5 mm | **nur falls die vorhandene nicht 2,5 mm dick ist** | |

### Summe

Grob **260–300 €**. Der größte Posten ist die Fernsteuerung (~85 €), die ist aber auch für
spätere Projekte weiter nutzbar.

## Später: Kamera

Die Kamera kommt in einer späteren Version dazu. Die Platine wird **jetzt schon** so gebaut,
dass das ohne Umbau geht: 5-V-Regler mit ≥ 1,5 A und der Anschluss **J5 (5 V, GND)** für
Kamera und Videosender. Das kostet jetzt fast nichts und hält die Tür offen, genau wie die
GPS-Pads.

Geplant ist analoges FPV (Live-Bild in der Videobrille, Aufnahme über deren Rekorder):

| ✓ | Teil | Worauf achten | ca. |
|---|---|---|---|
| [ ] | **Analoge FPV-Kamera, Nano-Größe (14 mm)**, z.B. Caddx Ant | Eingang muss **5 V** können; ~2 g | 15–20 € |
| [ ] | **Kleiner 5,8-GHz-Videosender (VTX)** | Eingang **5 V**, **auf 25 mW einstellbar** (in Deutschland das Maximum), Kanal per **Taste** einstellbar | 15–20 € |
| [ ] | **5,8-GHz-Antenne** | **Stecker muss zum VTX passen** (meist U.FL/IPEX) | ~5 € |
| [ ] | **Videobrille mit Rekorder (DVR)**, z.B. Eachine EV800D | analog 5,8 GHz, **mit DVR**, dann wird das Video gleich aufgenommen | 80–100 € |

> **Warum diese Kombination zusammenpasst:**
> - Kamera und VTX hängen am **5-V-Ausgang unserer Platine**. Dadurch braucht die Kamera
>   **keinen einzigen GPIO**, die Pinbelegung des XIAO bleibt unverändert.
> - Der VTX wird per Taste eingestellt, nicht per SmartAudio, weil SmartAudio einen freien
>   UART bräuchte, und den haben wir nicht.
> - Kein Bildschirm-Overlay (OSD) im Video: ESP-FC hat dafür keinen Chip. Die Akkuspannung
>   kommt stattdessen über die ELRS-Telemetrie auf das Display der Pocket.
> - Video läuft auf **5,8 GHz**, Fernsteuerung und ESP-NOW auf **2,4 GHz**, also stören sie
>   sich nicht gegenseitig.

**Was die Kamera dann ändert:** ~8 g mehr (~172 g statt ~164 g) und etwa 10 % weniger
Flugzeit (geschätzt ~10–16 min statt 11–18). Die Rechnung: Schwebeleistung wächst mit
Masse^1,5, also (172/164)^1,5 ≈ 1,07, dazu etwa 2 W für Kamera und Sender. Zusatzkosten
~120–150 €.

## Vorschriften (mit den Eltern klären)

- **Drohnen-Haftpflichtversicherung** ist in Deutschland Pflicht, für jede Drohne, auch ohne
  Kamera.
- *Erst wenn die Kamera dazukommt:* Betreiber beim Luftfahrt-Bundesamt (LBA) registrieren
  (bei Minderjährigen die Eltern), mit Videobrille nur mit Beobachter fliegen, Videosender
  auf höchstens 25 mW.

## Was „ESP-FC-kompatibel" überhaupt heißt

Eine Frage, die in der Recherche mehrfach auftauchte und die sich lohnt, in der Arbeit zu
klären. Die Kette ist:

```
Firmware  ->  Regler  ->  Motor
```

**Nur der Regler spricht mit der Firmware.** Der Motor sieht lediglich drei Phasen vom
Regler und weiß nichts davon, welche Software im Flugrechner läuft. „Ist dieser Motor mit
ESP-FC kompatibel?" ist deshalb keine sinnvolle Frage. Bei Motoren zählen KV-Zahl zur
Zellenzahl, Lochbild und Wellendurchmesser.

- **HAKRC 15A 4-in-1:** BLHeli_S auf EFM8BB21, DShot600 → **ja, kompatibel**, am
  ESP-FC-Quelltext geprüft.
- **Happymodel EX1204:** firmwareunabhängig. Passt mechanisch (9 × 9 mm M2, 1,5-mm-Welle)
  und elektrisch zum Regler.

## Hinweise zum Bestellen

- **Vier gleiche Motoren sind in Ordnung**, auch wenn Anzeigen CW/CCW unterscheiden: Bei
  1,5-mm-Wellen werden die Propeller aufgesteckt, es gibt kein Gewinde, das sich losdrehen
  könnte. Die Drehrichtung wird in der Regler-Firmware gesetzt oder durch Tauschen zweier
  Phasenleitungen.
- **Bei den Propellern brauchen wir dagegen beide Drehrichtungen.** Genau daran ist der
  Holz-Bausatz aus Schritt 1 gescheitert.
- **Ersatz mitbestellen, wo es billig ist:** Propeller, Sensormodule, ein fünfter Motor, der
  zweite Regler (ist schon drin). Der erste Absturz kommt bestimmt.
- **Später bei Kamera, VTX und Antenne vor dem Kauf prüfen:** Eingangsspannung 5 V möglich?
  Antennenstecker passend? Das sind die zwei häufigsten Fehlkäufe.
- Zwei verschiedene Verkäufer heißt zwei Sendungen, zwei Versandkosten und
  unterschiedliche Ankunftszeiten.

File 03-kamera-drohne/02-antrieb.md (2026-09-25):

# Antrieb: Motoren, Regler, Akku

*Warum aus „eigene Steuerplatine" zwangsläufig „zwei Akkuzellen" folgt.*

## Bürstenlos statt Bürsten — der Unterschied zu Schritt 2

Die ESP-FLY aus Schritt 2 fährt vier **Coreless-Motoren** über je einen MOSFET. Ein MOSFET
ist ein Schalter: Strom an, Strom aus, und über die Einschaltdauer regelt man die Drehzahl.
Das ist einfach, und deshalb sind kleine Spielzeug-Drohnen so gebaut.

Ein **bürstenloser Motor** funktioniert anders. Er hat drei Wicklungen, und ein Regler muss
sie in der richtigen Reihenfolge und zum richtigen Zeitpunkt bestromen — er muss also
wissen, wo der Rotor gerade steht. Dafür braucht es **drei Halbbrücken pro Motor** und eine
Elektronik, die aus der zurückkommenden Spannung (Gegen-EMK) die Rotorlage errechnet.

> **Kernsatz für die Arbeit:** Ein bürstenloser Regler ist kein größerer Schalter. Er ist
> ein anderes Gerät. Wer „Motortreiber" für bürstenlos sagt, meint einen **Regler (ESC)**.

Dieselbe Erkenntnis in der Gegenrichtung: **Die ESP-FLY-Platine aus Schritt 2 lässt sich
nicht weiterverwenden.** Ihre Ausgänge sind Gate-Ansteuerungen für Bürstenmotoren, keine
Reglersignale. Wiederverwendbar sind aus dem Bausatz das **XIAO-ESP32-S3-Modul selbst** und
Kaspars Handy-App — nicht die Platine.

## Warum es 2S werden musste

Ein eigenes Steuerboard braucht einen **getrennten** Regler, den es ansteuern kann. Die
Recherche im Handel ergab einen klaren Befund:

> **Getrennte 4-in-1-Regler gibt es erst ab zwei Zellen (2S).** Alles, was für eine Zelle
> (1S) angeboten wird, ist ein „AIO" — ein Board mit **fest verbauter** Flugsteuerung. Für
> unser eigenes Board unbrauchbar.

Das ist kein Zufall und kein einzelnes Produkt: Bei FPV24, dem größten deutschen Händler,
ist im ganzen Sortiment „FC, ESC, AIO & Stacks" **kein einziger** 4-in-1-Regler unter 6S
und unter 45 A gelistet. Alles Kleine wird heute als AIO verkauft. Lieferbar ist die Klasse
noch bei den chinesischen Versendern (Banggood, AliExpress) mit EU-Versand.

**Die Folge:** zwei Akkuzellen in Reihe statt einer. Zwei 18650 wiegen ~89 g statt ~45 g.
Der 1S-Weg mit fertigem AIO wäre etwa **15 % länger geflogen**. Das ist der Preis für den
eigenen Entwurf, und er ist vertretbar — eine gute Stelle in der Arbeit, um zu zeigen, dass
technische Entscheidungen Folgekosten haben.

**Und ein Hinweis für später:** Wenn in Stufe 2 der eigene Regler kommt, **bei 2S bleiben**.
Ein Wechsel zurück auf 1S würde andere Motoren erfordern, weil die KV-Zahl an der
Zellenzahl hängt (siehe unten). Das ganze Gerät konsequent auf 2S auszulegen ist billiger
und ehrlicher.

## Motoren: 1204 mit 6500 KV

Die **KV-Zahl** gibt an, wie viele Umdrehungen pro Minute ein Motor pro angelegtem Volt
macht. Sie ist deshalb direkt an die Zellenzahl gekoppelt: Was an einer Zelle 11500 KV
braucht, braucht an zwei Zellen etwa die **Hälfte**.

| Motor | KV | Zellen | Gewicht | Bemerkung |
|---|---|---|---|---|
| **HappyModel EX1204** | 6500 | 2–3S | ~6 g | für 3"-Toothpicks gemacht, günstig — **gewählt** |
| T-Motor F1204 | 6500 | 2–3S | ~6 g | bessere Verarbeitung, teurer |
| iFlight XING Nano 1204 | 6500 | 2–3S | 6,5 g | |
| HappyModel EX1202.5 | 6400 | 1–2S | 4,5 g | leichter, aber für 2,8" zu wenig Schub |

Alle haben **9 × 9 mm M2-Lochbild und 1,5-mm-Welle** — das Lochbild im Rahmen ist also von
der endgültigen Motorwahl unabhängig, und die Propeller passen auf jeden davon.

**Warum 1204 und nicht die leichteren 1202.5:** Mit 2,8"-Propellern an 2S ergeben die 1204
etwa **3,5–4:1 Schub-zu-Gewicht** — genug Reserve für Wind, ohne dass die Drohne nervös
wird. Die 1202.5 wären 6 g leichter, lägen aber bei ~2,5:1, und das ist für draußen zu
knapp.

> Ein Wert zwischen 3:1 und 4:1 gilt als gutmütig. Ein Rennquad hat 8:1 — das ist für einen
> ersten Eigenbau eher gefährlich als hilfreich.

## Regler: HAKRC 15A 4-in-1

Ursprünglich geplant war der Flywoo GOKU BS13A. Der ist **überall ausverkauft** und wird
offenbar nicht mehr produziert — ein gutes Beispiel dafür, dass Bauteilverfügbarkeit Teil
der Konstruktion ist. Ersatz:

| | |
|---|---|
| Spannung | 2–4S |
| Dauerstrom | 15 A je Kanal, Spitze 20 A |
| ESC-Chip | **EFM8BB21F16G** — derselbe wie im Flywoo |
| Firmware ab Werk | BLHeli_S BL16.7 |
| Protokolle | DShot150/300/600, Oneshot, Multishot, PWM |
| Lochbild | **20 × 20 mm** |
| Gewicht | 5,2 g |
| Besonderheit | eingebauter Strommesser, 4-lagige Platine, 3 oz Kupfer |
| Preis | ~20,60 € inkl. EU-Mehrwertsteuer |

**Warum genau der:** 15 A sind für unsere ~9 A im Schwebeflug richtig dimensioniert (der
25-A-Bruder wäre nur schwerer). 2–4S deckt unsere 2S ab. Und der Chip ist derselbe wie beim
ursprünglich geplanten Flywoo — der Weg zu besserer Regler-Firmware bleibt damit offen:

> **Bluejay statt BLHeli_S.** Die ab Werk aufgespielte Firmware lässt sich auf das offene
> **Bluejay** umflashen. Das bringt **bidirektionales DShot**, also Drehzahl-Rückmeldung
> vom Regler an die Flugsteuerung und damit RPM-Filterung. ESP-FC unterstützt das
> ausdrücklich. Kostet nichts außer einer halben Stunde — und ist ein schönes eigenes
> Kapitel über Regler-Firmware.
>
> Praktisch geht das **durch den XIAO hindurch**: ESP-FC hat eine ESC-Durchleitung
> (`MSP_PASSTHROUGH_ESC_4WAY`), BLHeliSuite spricht also über den Flugrechner mit den
> Reglern. Kein separater Programmieradapter nötig.

**Was sich gegenüber der ursprünglichen Planung änderte:** 5,2 g statt 2,5 g und
**20 × 20 mm statt 16 × 16 mm Lochbild**. Die Trägerplatine muss deshalb auf 20 × 20
ausgelegt werden. Die 2,7 g Mehrgewicht ändern an der Flugzeit praktisch nichts.

### Rückfallweg: vier Einzelregler

Falls auch der HAKRC ausgeht — Einzelregler für 2–4S gibt es reichlich (SPEDIX ES25 ~10,50 €,
HSKRC 20A ~9 €, HGLRC 30A ~9,20 €). Vier Stück kosten etwa so viel wie ein 4-in-1, wiegen
zusammen mehr und brauchen mehr Lötstellen. **Dafür hat das für ein Schulprojekt ein
Argument:** Geht beim Absturz einer kaputt, tauscht man einen Regler für 10 € statt der
ganzen Platine.

## Akku: zwei 18650-Zellen in Reihe

Ausdauer-Drohnen fliegen **Lithium-Ionen-Rundzellen** statt der sonst üblichen LiPos. Der
Grund: Rundzellen speichern deutlich mehr Energie pro Gramm, können dafür weniger Strom
liefern. Für ein Gerät, das gemütlich schweben soll, ist das der richtige Tausch — für ein
Rennquad wäre es der falsche.

**Und genau hier wird es rechnerisch interessant.** Im Schwebeflug braucht unser Gerät
grob 60–70 W, bei 7,4 V also **~9 A**. Im Vollgas ziehen die vier Motoren zusammen aber
**~36 A** — und in einer Reihenschaltung fließt dieser Strom durch **jede einzelne Zelle**.

Aus den Messungen von lithiumionfpv.com (die Zellen unter echter Last testen, nicht nach
Herstellerangabe):

| Zelle | real belastbar | Herstellerangabe | geeignet? |
|---|---|---|---|
| **Eve 30PL** | 40 A | — | **ja** |
| **Ampace JP30** | 45 A | — | **ja** |
| Linkdata 65P | 25 A | 52 A | nein |
| Samsung 25R | 20 A | — | nein |

**Entschieden: Eve 30PL oder Ampace JP30.** Beide reichen, mit wenig Luft nach oben.

> Der Unterschied zwischen angegebener und gemessener Belastbarkeit (52 A gegen 25 A bei
> der Linkdata) ist ein lohnendes Detail für die schriftliche Arbeit: Datenblattwerte sind
> nicht immer Messwerte.

Der Zellhalter bekommt **Kupferkontakte** — gemessen besser als die üblichen
Messingkontakte, weil Kupfer besser leitet und bei 36 A jeder Milliohm zählt.

## Gewichtsbudget

| Teil | Gewicht |
|---|---|
| Rahmen 2,5 mm CF, 90 × 90 mm | 12,0 g |
| 4 × 1204-Motor | 24,0 g |
| 4-in-1-Regler HAKRC 15A | 5,2 g |
| eigene Trägerplatine, fertig bestückt | 10,0 g |
| XIAO ESP32-S3 | 3,5 g |
| ELRS-Empfänger | 1,0 g |
| 4 × 2,8"-Propeller | 4,0 g |
| Zellhalter, Kabel, Stecker | 12,0 g |
| Schrauben, Kleinteile | 3,0 g |
| **Trocken** | **~74,7 g** |
| + 2 × 18650 Eve 30PL | 89,2 g |
| **Abflug** | **~164 g** |

Daraus die Flugzeitschätzung von **11–19 Minuten** — das untere Ende des Ziels von
15–30 min, nicht die Mitte. Der einzige wirksame Hebel wäre weniger Trockengewicht.

> **Achtung für den Rahmen:** 164 g Abfluggewicht sind mehr als jeder in den ausgewerteten
> Bruchtests geprüfte 3"-Aufbau. Zusatzmasse ist genau das, was Rahmen zerlegt hat — bei
> 2,5 mm Carbon bleiben und an den Armansätzen nicht sparen.

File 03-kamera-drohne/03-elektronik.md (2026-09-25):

# Elektronik: Flugrechner, Software, Fernsteuerung

*Derselbe Mikrocontroller wie in Schritt 2 — aber eine andere Software und eine völlig
andere Leistungsklasse.*

## Der Flugrechner: XIAO ESP32-S3

Bewusst derselbe Mikrocontroller wie in der ESP-FLY aus Schritt 2. Damit ist Schritt 3
keine Neuanfang, sondern eine **Weiterentwicklung**: Kaspar kennt das Modul, die
Entwicklungsumgebung und das Flashen bereits.

> **Wichtig, weil es leicht übersehen wird:** Der XIAO ESP32-S3 hat **keinen Kreisel an
> Bord**. In der ESP-FLY saß der Sensor auf dem Trägerboard. Ohne eigenes Kreiselmodul gibt
> es keine Flugregelung — das ist der Posten in der Bestellliste, den man am leichtesten
> vergisst und der am sichersten alles aufhält.

## Die Software: ESP-FC statt ESP-Drone

In Schritt 2 lief **ESP-Drone** (von Espressif). Die kann keine bürstenlosen Motoren
ansteuern: Im Quelltext ist Brushless angelegt, aber nicht aktiviert, und die Ausgänge
sprechen Bürsten-PWM. Sie ließe sich erweitern — das wäre aber ein eigenes, großes Projekt.

**Entschieden: [ESP-FC](https://github.com/rtlopez/esp-fc)** von rtlopez. Eine offene
Flugsoftware, die Betaflight nachempfunden ist. Was sie mitbringt:

| | |
|---|---|
| Zielplattform | ESP32-S3 ausdrücklich unterstützt |
| Reglerprotokolle | **DShot150/300/600**, auch bidirektional |
| Empfänger | CRSF/ELRS, SBUS, IBUS, PPM **und ESP-NOW — gleichzeitig im selben Firmware-Stand** |
| Kreisel | MPU6050, MPU6000/6500/9250, ICM20602, ICM42688, BMI160 |
| Weiteres | Barometer, GPS, Blackbox, MSP- und CLI-Schnittstelle |
| Rahmenform | nur `QUADX` — vier Motoren, das passt |

Konfiguriert wird mit dem **Betaflight-Configurator** über USB, oder drahtlos über den
eingebauten Zugangspunkt `ESP-FC` unter `tcp://192.168.4.1:1111`.

### Was Kaspar dabei selbst programmiert

Nicht die Flugregelung — die zu schreiben wäre unrealistisch und auch nicht der Punkt.
Selbst gemacht wird:

- die **Konfiguration** der Firmware auf die eigene Hardware (siehe Pinbelegung unten),
- die **Anpassung von Kaspars Handy-App** auf den ESP-NOW-Transport,
- später der **Raspberry-Pi-Code** für die Gestenerkennung (Stufe 3),
- und in Stufe 2 die Inbetriebnahme des eigenen Reglers mit AM32.

## Steuerarchitektur: drei Wege auf einen Eingang

ESP-FC nimmt mehrere Eingänge gleichzeitig entgegen. Das nutzen wir bewusst — und es ist
der eleganteste Teil des ganzen Entwurfs:

**ELRS über CRSF (UART)** — die ernsthafte Fernsteuerung. Kilometer Reichweite, richtiges
Failsafe, funktioniert auch, wenn WLAN stört. Empfänger ~10–15 €, Sender (z.B. RadioMaster
Pocket) ~100 €. **Das ist der Sicherheitsanker: was immer sonst passiert, die Fernsteuerung
übersteuert.**

**ESP-NOW** — kurze Strecke, wenig Latenz. Hier hängt Kaspars iPhone-App an, und später der
Raspberry Pi mit der Gestenerkennung.

**MSP** — zum Einstellen und Auslesen mit dem Betaflight-Configurator.

> **Der Gewinn:** Gestensteuerung, Handy-App und Fernsteuerung sprechen **denselben
> Eingang** — RC-Kanäle. Wer später etwas Neues anschließen will, muss am Fluggerät nichts
> ändern. Und es gibt immer eine Instanz, die alles übersteuern kann. Das ist die
> Bedingung dafür, dass man so ein Gerät überhaupt fliegen lässt.

## Das Pin-Budget — die Entscheidung hinter der Sensorik

Der XIAO ESP32-S3 führt **elf GPIOs** heraus: 1–9, 43, 44. Mehr gibt es nicht, und das ist
knapp. Die Aufteilung:

| Funktion | Pins | Rest |
|---|---|---|
| 4 Motorsignale (DShot) | 4 | 7 |
| ELRS-Empfänger (UART) | 2 | 5 |
| **I2C-Bus** | 2 | 3 |
| Akkuspannung (ADC) | 1 | 2 |
| Summer | 1 | 1 |
| GPIO3 bleibt frei (Strapping-Pin) | — | 1 |

**Der entscheidende Punkt: I2C ist ein Bus.** Kreisel, Barometer und Magnetometer hängen
alle an denselben zwei Leitungen, jedes mit eigener Adresse. **Ein Barometer kostet also
null zusätzliche Anschlüsse.** Alles, was eine eigene Schnittstelle braucht — GPS über
UART — kostet dagegen zwei, und die haben wir nicht.

Daraus folgt die Sensorwahl, ausführlich in [`04-traegerplatine.md`](04-traegerplatine.md):
Kreisel und Barometer ja, Magnetometer und GPS nein.

### Warum I2C und nicht SPI

ESP-FC empfiehlt SPI für den Kreisel, weil es höhere Abtastraten erlaubt (Richtung 8 kHz
statt 1 kHz). SPI braucht aber **vier** Pins (SCK, MOSI, MISO, CS). Dann sind alle elf
belegt — **kein Barometer, kein Summer**.

**Entschieden: I2C.** Die höhere Abtastrate lohnt bei einem Rennquad, nicht bei einem
ruhigen Ausdauergerät. Höhenhaltung und Summer sind hier mehr wert. Wer später mehr
Regelrate will, opfert Summer und Spannungsmessung und nimmt einen ICM-42688 über SPI.

## Pinbelegung

Die Standardbelegung von ESP-FC auf dem ESP32-S3 passt **nicht** zum XIAO: Motoren liegen
dort auf GPIO 39–42 und der I2C-Takt auf GPIO 10 — **die gibt es am XIAO gar nicht.** Die
Pins müssen also zwingend umgelegt werden. Das ist vorgesehen, nicht geduldet: Im Quelltext
ist für dieses Ziel `ESPFC_SERIAL_REMAP_PINS` gesetzt.

| Funktion | XIAO-Beschriftung | GPIO |
|---|---|---|
| Motor 1 | D0 | 1 |
| Motor 2 | D1 | 2 |
| Motor 3 | D3 | 4 |
| Motor 4 | D8 | 7 |
| Kreisel/Barometer SDA | D4 | 5 |
| Kreisel/Barometer SCL | D5 | 6 |
| ELRS-Empfänger, Signal | D7 | 44 |
| ELRS-Empfänger, Telemetrie | D6 | 43 |
| Akkuspannung (über Teiler) | D9 | 8 |
| Summer | D10 | 9 |
| **frei lassen** | D2 | 3 |

> **Warum D2 frei bleibt:** GPIO3 ist am ESP32-S3 ein **Strapping-Pin** — sein Zustand beim
> Einschalten beeinflusst, wie der Chip startet. Als Motorausgang wäre das ein unnötiges
> Risiko.

### Die Befehle in der ESP-FC-Kommandozeile

```
set pin_output_0 1
set pin_output_1 2
set pin_output_2 4
set pin_output_3 7
set pin_i2c_sda 5
set pin_i2c_scl 6
set pin_input_adc_vbat 8
set pin_buzzer 9
set pin_input_rx -1        # PPM lag auf GPIO 6, den brauchen wir fuer SCL
set pin_spi_cs_0 -1        # SPI-Chipselects lagen auf 7 und 8
set pin_spi_cs_1 -1
set motor_pwm_protocol DSHOT300
set motor_poles 12
save
```

Anmerkungen:

- **DShot300 zum Anfangen**, nicht 600 — mehr Zeitreserve auf den Leitungen. Läuft es
  sauber, kann man hochgehen.
- `motor_poles 12` gilt für 1204-Motoren und wird für die Drehzahl-Telemetrie gebraucht.
- **Motorreihenfolge** nach Betaflight-Konvention QUADX: M1 hinten rechts, M2 vorne rechts,
  M3 hinten links, M4 vorne links. Die Drehrichtung ändert man durch Tauschen zweier
  Motorphasen oder in der Regler-Firmware.
- Die Signalleitungen sind **3,3-V-Logik**. BLHeli_S-Regler nehmen das an; auch fertige
  Flugsteuerungen geben 3,3 V aus.
- **Der ELRS-Empfänger braucht zusätzlich eine Umstellung im Configurator:** Im Reiter
  *Ports* muss die **Funktion** von Serial 0 von MSP auf *Serial RX* umgestellt werden,
  nicht nur der Pin. MSP bleibt über USB erreichbar.

## Geprüft am Quelltext (23.09.2026)

Nachgesehen im geklonten Stand von github.com/rtlopez/esp-fc:

- `TargetESP32s3.h` definiert `ESPFC_OUTPUT_COUNT 4` — vier Motorausgänge, und das Umlegen
  der Pins ist für dieses Ziel offiziell vorgesehen.
- Die DShot-Erzeugung läuft über die **RMT-Einheit** des ESP32, inklusive Umschalten auf
  Empfang für die bidirektionale Telemetrie. Der ESP32-S3 hat **genau vier**
  RMT-Sendekanäle — für vier Motoren reicht das exakt, Reserve gibt es keine. Ein fünfter
  Ausgang wäre nicht drin.
- Die Höhenhaltung (`MODE_ALTHOLD`) regelt auf die Steig- und Sinkrate aus der
  Höhenschätzung — die kommt vom **Barometer**. Ohne Barometer keine Höhenhaltung.
- ESP-FC kann **ESC-Durchleitung** (`MSP_PASSTHROUGH_ESC_4WAY`): Bluejay lässt sich durch
  den XIAO hindurch auf die Regler flashen.

**Ergebnis: XIAO ESP32-S3 + ESP-FC + HAKRC 15A passen zusammen.** Signalpegel 3,3 V,
DShot150/300/600 auf beiden Seiten, 2–4S deckt unsere 2S ab.

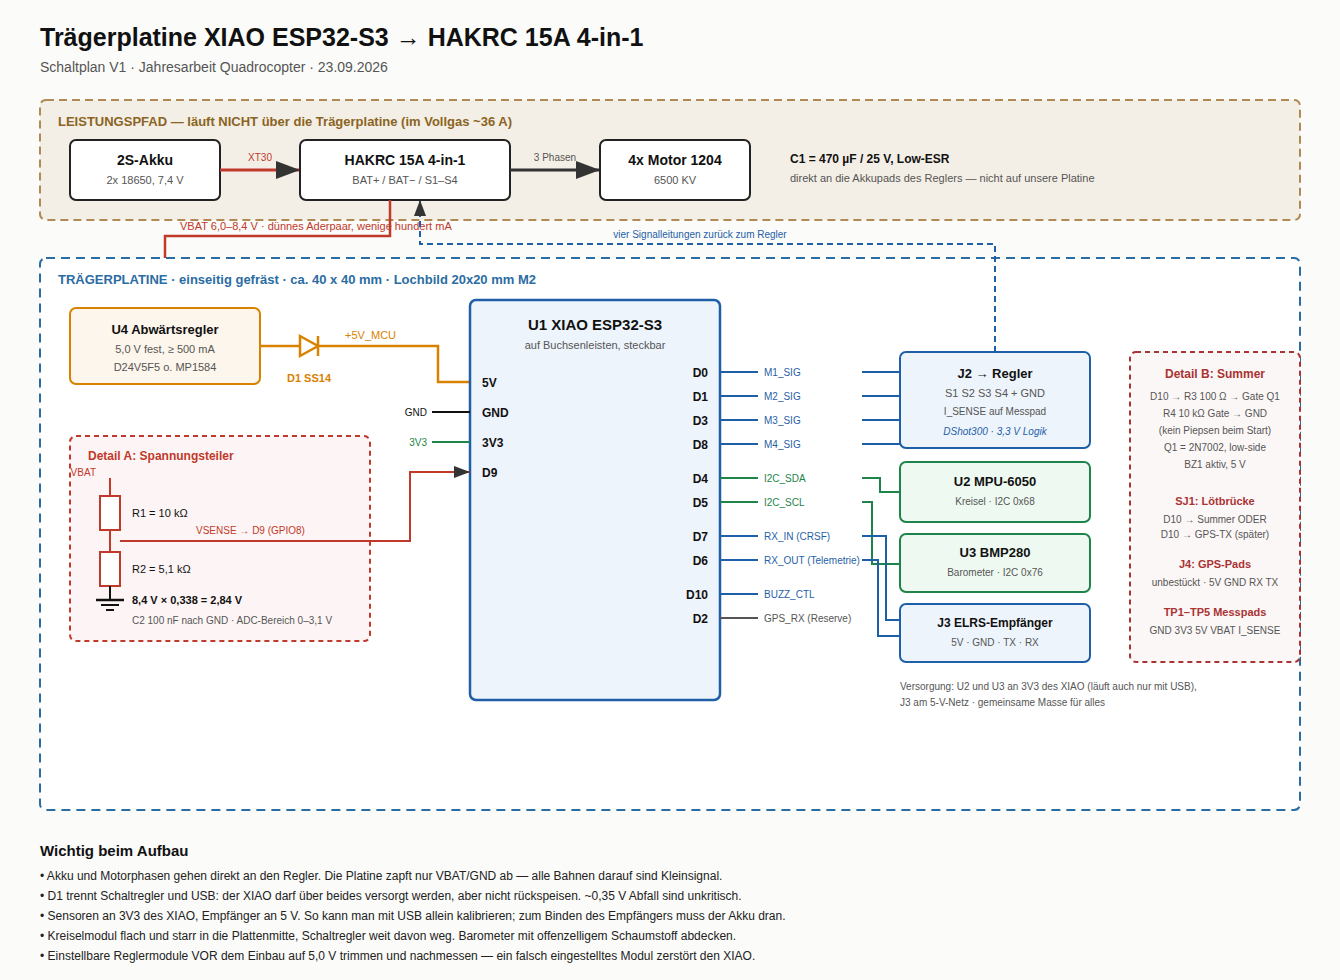
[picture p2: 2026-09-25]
03-kamera-drohne/bilder/traegerplatine-schaltplan.png

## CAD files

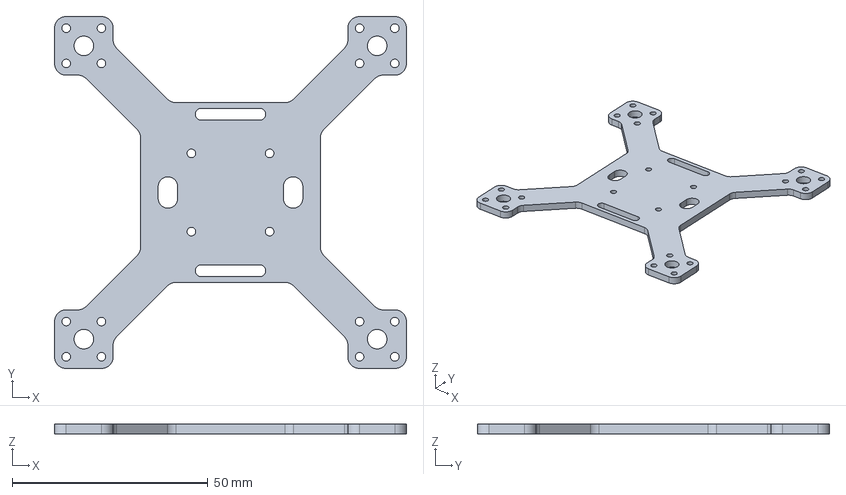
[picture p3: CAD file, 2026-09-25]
03-kamera-drohne/cad/rahmen.step
90.0 x 90.0 x 2.50 mm

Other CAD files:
03-kamera-drohne/cad/rahmen.dxf
03-kamera-drohne/cad/rahmen.stl

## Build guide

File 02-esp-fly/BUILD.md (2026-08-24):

# ESP-FLY: Firmware bauen und flashen — Schritt-für-Schritt

Diese Anleitung führt von Null bis zur fliegenden Drohne. Getestet auf **macOS**.

## Überblick — welche Projekte brauchen wir?

| Projekt | Was ist das? | Wie eingebunden |
|---|---|---|
| **esp-drone** | Die Flug-Software (Firmware) der Drohne | Submodul `esp-drone/` |
| **esp-idf** | Die Bau-Umgebung von Espressif (Compiler, Werkzeuge) | Submodul `esp-idf/` (v5.0) |
| *esp-now u. a.* | Zusatz-Bausteine der Firmware | lädt der Build automatisch nach |

`esp-drone` allein reicht nicht — sie ist nur der Quelltext. Zum *Übersetzen* in
ein Programm, das der Chip versteht, braucht man **ESP-IDF**.

---

## Schritt 0 — Projekt holen (inkl. Submodule)

```bash
git clone --recurse-submodules git@github.com:Kaspar667/jahresarbeit-klasse-8.git
cd jahresarbeit-klasse-8/02-esp-fly
```

Falls schon geklont, aber die Submodule fehlen (leere Ordner `esp-drone/`,
`esp-idf/`):

```bash
git submodule update --init --recursive
```

> ⚠️ ESP-IDF ist groß (~1,7 GB). Der erste Download dauert ein paar Minuten.

---

## Schritt 1 — ESP-IDF einmalig einrichten

ESP-IDF muss einmal seine Compiler/Werkzeuge herunterladen (nach `~/.espressif`):

```bash
cd esp-idf
./install.sh esp32s3
cd ..
```

---

## Schritt 2 — Firmware bauen

```bash
cd esp-drone
. ../esp-idf/export.sh        # lädt ESP-IDF ins Terminal (in JEDEM neuen Terminal nötig)
idf.py set-target esp32s3     # holt die ESP-FLY-Pins aus sdkconfig.defaults.esp32s3
idf.py build                  # baut die Firmware -> build/ESPDrone.bin
cd ..
```

Am Ende steht sinngemäß: `Project build complete.`

---

## Schritt 3 — Auf die Drohne flashen

Drohne per **USB-Kabel** an den Mac anstecken, dann:

```bash
./flash.sh
```

Das Skript findet ESP-IDF und den USB-Port automatisch. Alternativ Port angeben:

```bash
./flash.sh /dev/cu.usbmodem101
```

Fertig, wenn `Hash of data verified.` und `Hard resetting...` erscheinen.

---

## Schritt 4 — Fliegen

1. Handy ins WLAN **`ESP-DRONE_...`** einwählen — Passwort `12345678`.
2. **ESP-Drone App** (iOS/Android, von Espressif) öffnen → **Connect**.

---

## Kontrolle: Läuft die Drohne richtig? (Boot-Log lesen)

Nützlich zur Fehlersuche. Liest die Log-Ausgabe der Drohne über USB:

```bash
cd esp-drone
. ../esp-idf/export.sh
idf.py -p /dev/cu.usbmodem101 monitor      # beenden mit Strg+]
```

Gut ist:

```
SENSORS: MPU6050 I2C connection [OK].
SYS: systemTest = 1     COMM: crtpTest = 1     SYS: stabilizerTest = 1
```

---

## Häufige Probleme

| Symptom | Ursache | Lösung |
|---|---|---|
| `MPU6050 I2C connection [FAIL]` | falsche Pins / falsches Board-Target | `idf.py set-target esp32s3` (nimmt die richtigen ESP-FLY-Pins), neu bauen & flashen |
| App verbindet nicht | Sensor-Selbsttest scheitert (s. o.) | siehe oben — erst muss der MPU6050 `[OK]` sein |
| Kein `/dev/cu.usbmodem*` | Kabel/Port | anderes USB-Kabel (Datenkabel!), anderer Port; ggf. USB-Treiber |
| `VL53L1X`/`PMW3901`/`Z-down` `[FAIL]` | optionale Sensoren nicht verbaut | **normal** beim ESP-FLY — nur Warnungen, kein Problem |
| Build-Fehler `protocomm_security1` o. ä. | falsche ESP-IDF-Version | ESP-IDF muss **v5.0** sein (Submodul ist darauf gepinnt) |

---

## Warum diese ESP-IDF-Version?

Die Firmware `esp-drone` wurde für **ESP-IDF release/v5.0** geschrieben. Neuere
Versionen (v6.x) haben geänderte Schnittstellen und der Build schlägt fehl.
Das Submodul `esp-idf/` ist deshalb fest auf die passende v5.0-Version gepinnt.

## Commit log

2026-08-24 Jahresarbeit Kamera-Drohne: Projektstruktur mit 3 Bauschritten
    - Ueberblick + Ordner fuer 3 Schritte (Holzbausatz, ESP-FLY, Kamera-Drohne)
    - docs/ fuer die schriftliche Ausarbeitung
    - 02-esp-fly: ESP-FLY-Firmware als Submodul (spieker/esp-drone @ jahresarbeit-klasse-8)
    plus flash.sh und Dokumentation der Board-Anpassungen
2026-09-25 Schritt 3: Auslegung, Antrieb, Elektronik und Traegerplatine dokumentiert
    Der Ordner 03-kamera-drohne/ enthielt bisher nur einen Platzhalter. Die
    Planung ist inzwischen entschieden und wird hier festgehalten - jeweils mit
    Begruendung und verworfener Alternative, damit daraus die schriftliche
    Arbeit entstehen kann.
    - 01-auslegung.md Rahmen 9x9 cm, warum 3-Zoll-Propeller geometrisch nicht
    passen, Propellerwahl, Flugzeitschaetzung 11-19 min
    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
2026-09-25 Schritt 3: Bauplan von der Bestellung bis zum ersten Flug
2026-09-25 Schritt 3: Rahmen als parametrisches CAD-Modell (STEP, DXF, STL)
    Das Modell zeigt: Akku muss unter den Rahmen, Platinenecken liegen unter den Propellern.
    [rahmen.dxf, rahmen.step, rahmen.stl]
